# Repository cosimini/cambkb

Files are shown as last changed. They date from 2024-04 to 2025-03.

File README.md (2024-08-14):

# Yet another split keyboard with low profile Gateron switches

**Important note: tested, it works**
Now the hard part, try getting used to it.

**WARNING:** There's a mistake in the RJ-9 connector routing, I didn't consider that RJ9 cables are typically crimped mirrored, so a custom cable has to be made in order to use the design.

Basically a replica of any other split keyboard project you can find on github
* Pro micro controller
* Gateron low profile KS-33 switches with hot-swap sockets
* No OLED screen, LEDs or other shiny stuff

The main difference in the layout is that the positions of the thumb-keys is moved to the center with respect to more famous keyboards like the Lily58, more like the Voyager.
Vertical stagging of about 1/4 of a key size is applied in the vertical direction, between columns.
The distance between switches is 19mm and not 19.05mm like many other, I don't care it's not 3/4 of an inch.

The PCB is designed using KiCad. It is the same for both right and left side, depending on where components are soldered.
There's no 3D printed case or key support mask, but I'd like to implement it.

The reason for the double socket for the controller is that I was usure on which side I'd like to put the controller.

For the time being I'm not planning to implement QMK or similar things, key map is hardcoded in the code.
The code is based on the Arduino library because I'm lazy. For the same reason I'm using PlatformIO.

For the used switches and controller lib/footprint, credit to [foostan/kdb](https://github.com/foostan/kbd/tree/main).

# BOM
* Controllers: Any pro-micro close is fine, I used the cheapest one I found on Amazon. You can buy presoldered ones, the PCB is compatible with any orientation.
* Switches: Gatheron low profile switches, KS-33 footprint, I used [those ones](https://www.gateron.com/products/gateron-ks-33-low-profile-20-banana-switch?VariantsId=10734).
* Sockets for the switches: The ones associated to the KS-33 footprint ([those](https://www.gateron.com/products/gateron-low-profile-switch-hot-swap-pcb-socket?VariantsId=10234)).
* Diodes: BAT85 are the ones I used, but any signal diode with similar specs should be fine.
* Resistors: There's a resistor in series to the voltage sourcing pin. To prevent accidental shorts, a 1k resistor is placed in series. Those can be replaced by a jumper wire. Note I used DIN0204, a kind of small size trough hole package.
* Sockets for the controller: If you don't want to solder the controllers to the PCB, you can use any 2.54mm socket.
* RJ9 socket: It is a standard, any trough hole socket is fine.
* RJ9 Cable: **WARNING** as mentioned above, you need to make your own cable, as the common telephone ones has mirrored connected plugs at each end (i.e. in my design each cable must end on the same size of the plug).

# Pictures of the result





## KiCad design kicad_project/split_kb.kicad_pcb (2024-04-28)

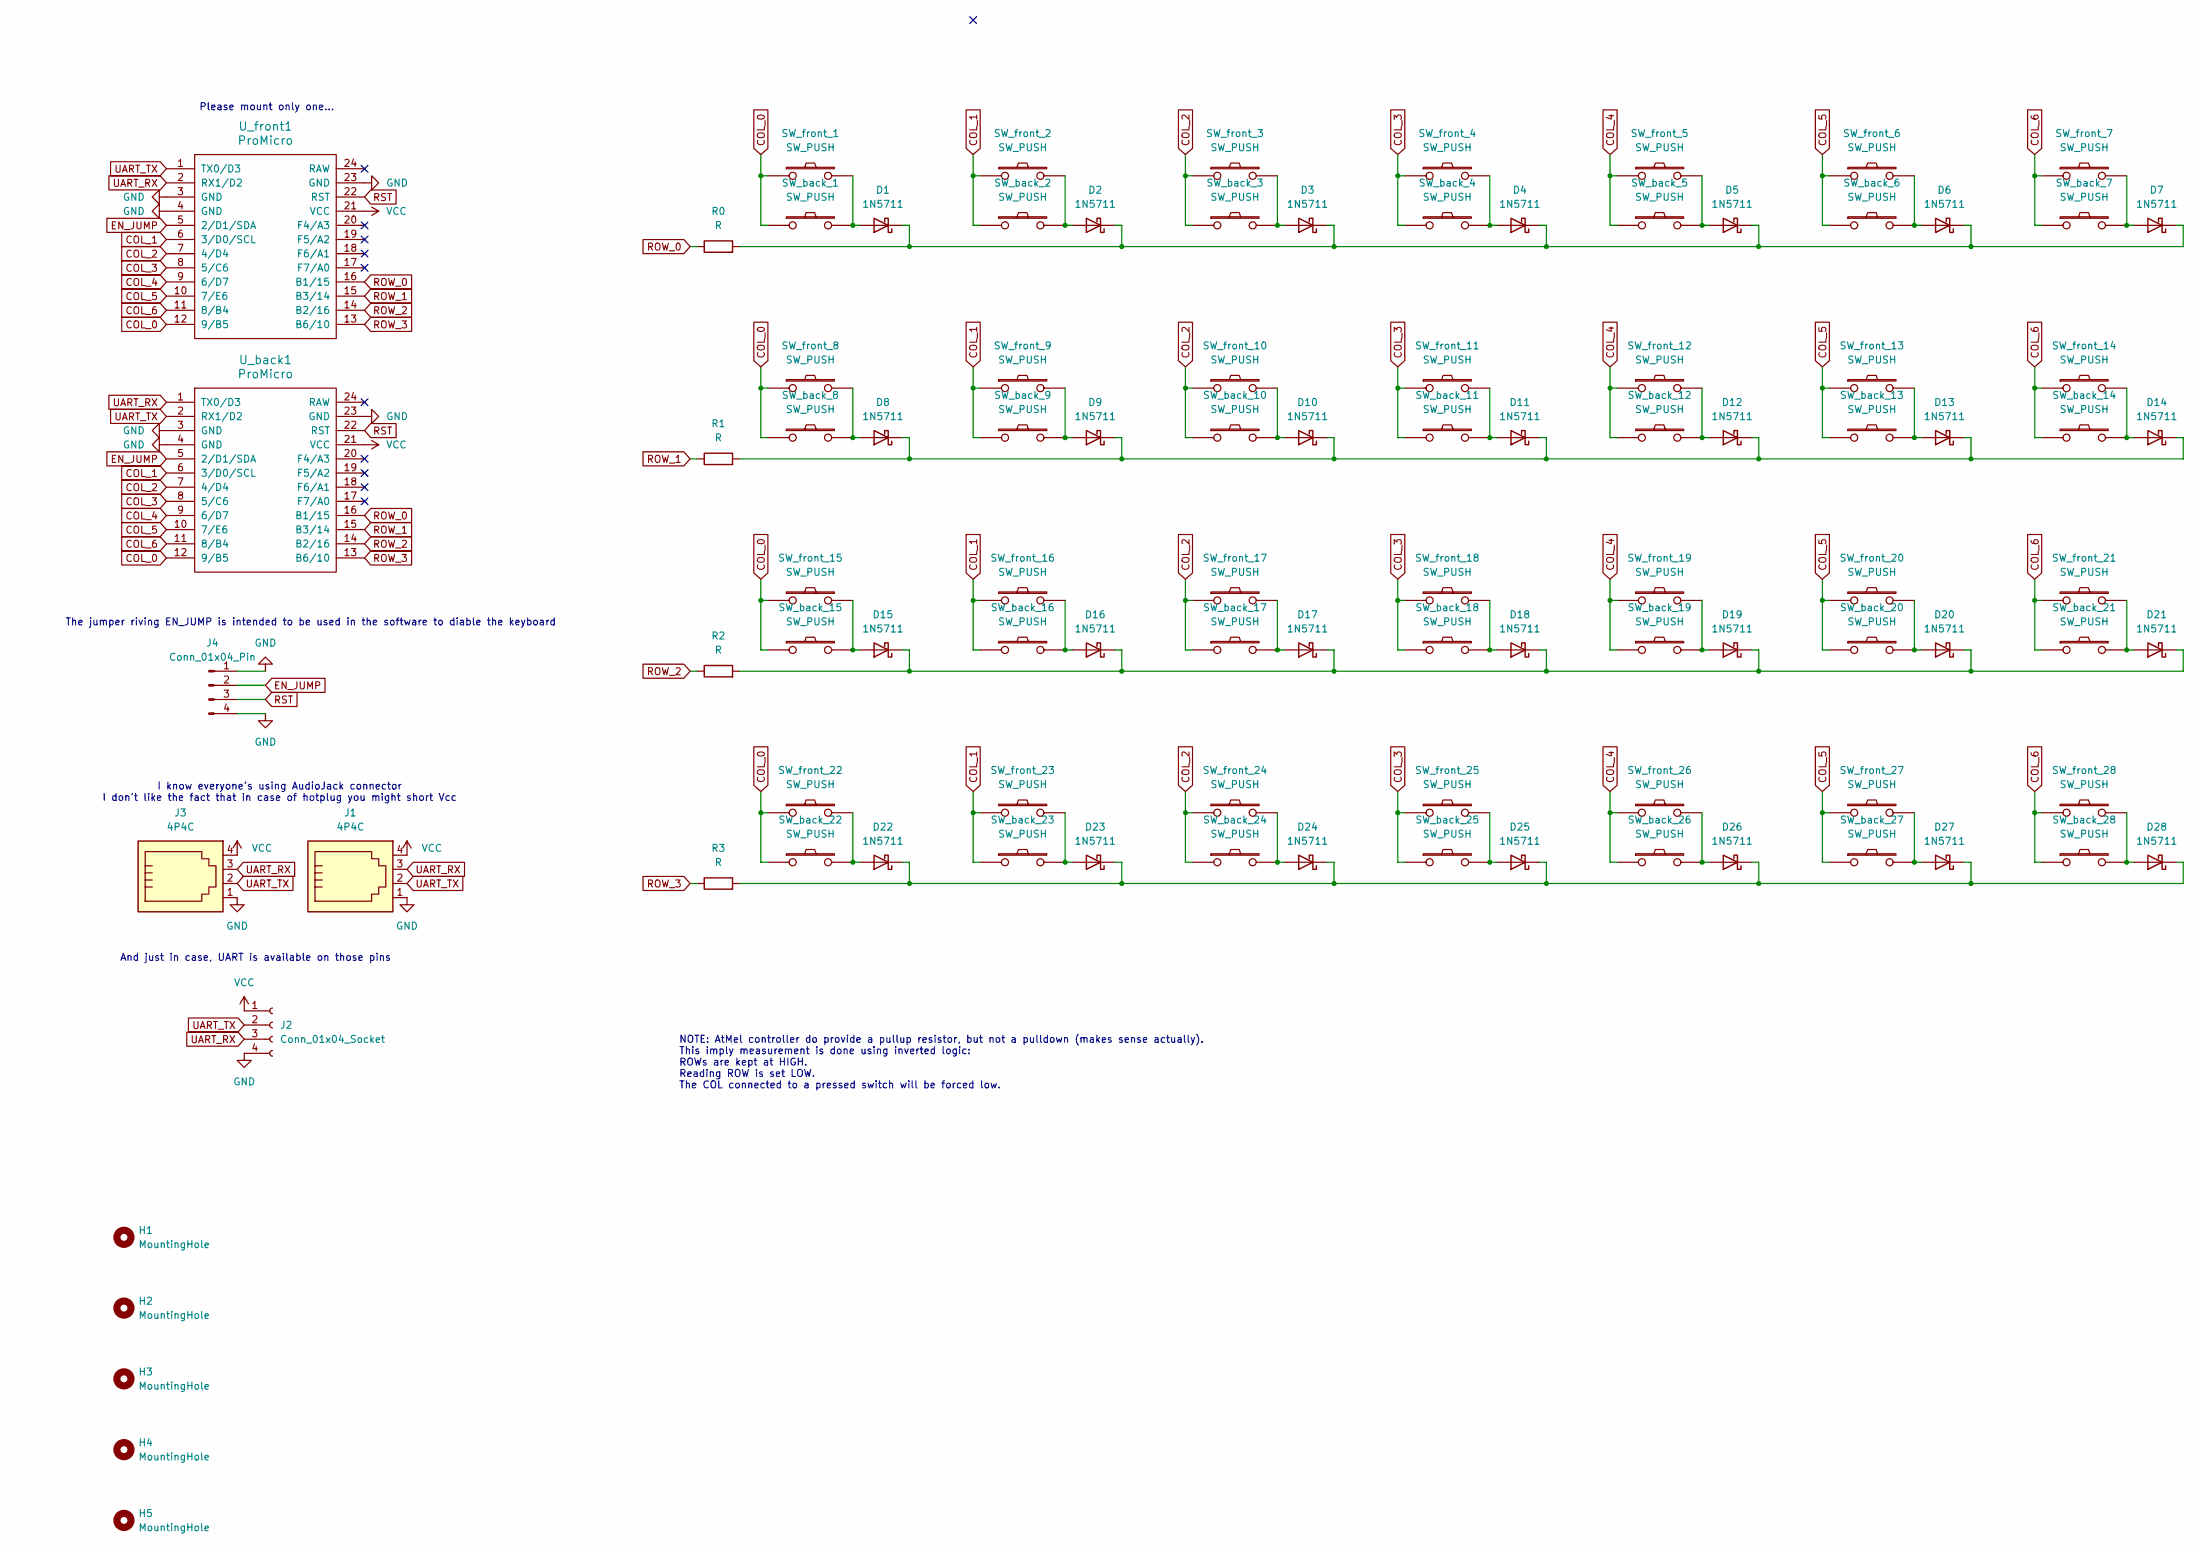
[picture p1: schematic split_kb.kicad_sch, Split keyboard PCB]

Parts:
D1, D2, D3, D4, D5, D6, D7, D8, D9, D10, D11, D12, D13, D14, D15, D16, D17, D18, D19, D20, D21, D22, D23, D24, D25, D26, D27, D28: 1N5711; D_DO-35_SOD27_P7.62mm_Horizontal
H1, H2, H3, H4, H5: MountingHole; MountingHole_3mm_Pad_Via
J1, J3: 4P4C; RJ9_Evercom_5301-440xxx_Horizontal
J2: Conn_01x04_Socket; PinHeader_1x04_P2.54mm_Vertical
J4: Conn_01x04_Pin; PinHeader_1x04_P2.54mm_Vertical
R0, R1, R2, R3: R; R_Axial_DIN0204_L3.6mm_D1.6mm_P5.08mm_Horizontal
SW_back_1, SW_back_2, SW_back_3, SW_back_4, SW_back_5, SW_back_6, SW_back_7, SW_back_8, SW_back_9, SW_back_10, SW_back_11, SW_back_12, SW_back_13, SW_back_14, SW_back_15, SW_back_16, SW_back_17, SW_back_18, SW_back_19, SW_back_20, SW_back_21, SW_back_22, SW_back_23, SW_back_24, SW_back_25, SW_back_26, SW_back_27, SW_back_28: SW_PUSH; keyswitch_gateron_low_profile_hotswap_1u
SW_front_1, SW_front_2, SW_front_3, SW_front_4, SW_front_5, SW_front_6, SW_front_7, SW_front_8, SW_front_9, SW_front_10, SW_front_11, SW_front_12, SW_front_13, SW_front_14, SW_front_15, SW_front_16, SW_front_17, SW_front_18, SW_front_19, SW_front_20, SW_front_21, SW_front_22, SW_front_23, SW_front_24, SW_front_25, SW_front_26, SW_front_27, SW_front_28: SW_PUSH; keyswitch_gateron_low_profile_hotswap_1u
U_back1: ProMicro
U_front1: ProMicro

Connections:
COL_0: SW_back_1.1, SW_back_8.1, SW_back_15.1, SW_back_22.1, SW_front_1.1, SW_front_8.1, SW_front_15.1, SW_front_22.1, U_back1.12 (9/B5), U_front1.12 (9/B5)
COL_1: SW_back_2.1, SW_back_9.1, SW_back_16.1, SW_back_23.1, SW_front_2.1, SW_front_9.1, SW_front_16.1, SW_front_23.1, U_back1.6 (3/D0/SCL), U_front1.6 (3/D0/SCL)
COL_2: SW_back_3.1, SW_back_10.1, SW_back_17.1, SW_back_24.1, SW_front_3.1, SW_front_10.1, SW_front_17.1, SW_front_24.1, U_back1.7 (4/D4), U_front1.7 (4/D4)
COL_3: SW_back_4.1, SW_back_11.1, SW_back_18.1, SW_back_25.1, SW_front_4.1, SW_front_11.1, SW_front_18.1, SW_front_25.1, U_back1.8 (5/C6), U_front1.8 (5/C6)
COL_4: SW_back_5.1, SW_back_12.1, SW_back_19.1, SW_back_26.1, SW_front_5.1, SW_front_12.1, SW_front_19.1, SW_front_26.1, U_back1.9 (6/D7), U_front1.9 (6/D7)
COL_5: SW_back_6.1, SW_back_13.1, SW_back_20.1, SW_back_27.1, SW_front_6.1, SW_front_13.1, SW_front_20.1, SW_front_27.1, U_back1.10 (7/E6), U_front1.10 (7/E6)
COL_6: SW_back_7.1, SW_back_14.1, SW_back_21.1, SW_back_28.1, SW_front_7.1, SW_front_14.1, SW_front_21.1, SW_front_28.1, U_back1.11 (8/B4), U_front1.11 (8/B4)
EN_JUMP: J4.2, U_back1.5 (2/D1/SDA), U_front1.5 (2/D1/SDA)
GND: J1.1, J2.4, J3.1, J4.1, J4.4, U_back1.3 (GND), U_back1.4 (GND), U_back1.23 (GND), U_front1.3 (GND), U_front1.4 (GND), U_front1.23 (GND)
unnamed: D1.2 (A), SW_back_1.2, SW_front_1.2
unnamed: D1.1 (K), D2.1 (K), D3.1 (K), D4.1 (K), D5.1 (K), D6.1 (K), D7.1 (K), R0.2
unnamed: D2.2 (A), SW_back_2.2, SW_front_2.2
unnamed: D3.2 (A), SW_back_3.2, SW_front_3.2
unnamed: D4.2 (A), SW_back_4.2, SW_front_4.2
unnamed: D5.2 (A), SW_back_5.2, SW_front_5.2
unnamed: D6.2 (A), SW_back_6.2, SW_front_6.2
unnamed: D7.2 (A), SW_back_7.2, SW_front_7.2
unnamed: D8.2 (A), SW_back_8.2, SW_front_8.2
unnamed: D9.2 (A), SW_back_9.2, SW_front_9.2
unnamed: D10.2 (A), SW_back_10.2, SW_front_10.2
unnamed: D8.1 (K), D9.1 (K), D10.1 (K), D11.1 (K), D12.1 (K), D13.1 (K), D14.1 (K), R1.2
unnamed: D11.2 (A), SW_back_11.2, SW_front_11.2
unnamed: D12.2 (A), SW_back_12.2, SW_front_12.2
unnamed: D13.2 (A), SW_back_13.2, SW_front_13.2
unnamed: D14.2 (A), SW_back_14.2, SW_front_14.2
unnamed: D15.2 (A), SW_back_15.2, SW_front_15.2
unnamed: D15.1 (K), D16.1 (K), D17.1 (K), D18.1 (K), D19.1 (K), D20.1 (K), D21.1 (K), R2.2
unnamed: D16.2 (A), SW_back_16.2, SW_front_16.2
unnamed: D17.2 (A), SW_back_17.2, SW_front_17.2
unnamed: D18.2 (A), SW_back_18.2, SW_front_18.2
unnamed: D19.2 (A), SW_back_19.2, SW_front_19.2
unnamed: D20.2 (A), SW_back_20.2, SW_front_20.2
unnamed: D21.2 (A), SW_back_21.2, SW_front_21.2
unnamed: D22.2 (A), SW_back_22.2, SW_front_22.2
unnamed: D22.1 (K), D23.1 (K), D24.1 (K), D25.1 (K), D26.1 (K), D27.1 (K), D28.1 (K), R3.2
unnamed: D23.2 (A), SW_back_23.2, SW_front_23.2
unnamed: D24.2 (A), SW_back_24.2, SW_front_24.2
unnamed: D25.2 (A), SW_back_25.2, SW_front_25.2
unnamed: D26.2 (A), SW_back_26.2, SW_front_26.2
unnamed: D27.2 (A), SW_back_27.2, SW_front_27.2
unnamed: D28.2 (A), SW_back_28.2, SW_front_28.2
ROW_0: R0.1, U_back1.16 (B1/15), U_front1.16 (B1/15)
ROW_1: R1.1, U_back1.15 (B3/14), U_front1.15 (B3/14)
ROW_2: R2.1, U_back1.14 (B2/16), U_front1.14 (B2/16)
ROW_3: R3.1, U_back1.13 (B6/10), U_front1.13 (B6/10)
RST: J4.3, U_back1.22 (RST), U_front1.22 (RST)
UART_RX: J1.3, J2.3, J3.3, U_back1.1 (TX0/D3), U_front1.2 (RX1/D2)
UART_TX: J1.2, J2.2, J3.2, U_back1.2 (RX1/D2), U_front1.1 (TX0/D3)
VCC: J1.4, J2.1, J3.4, U_back1.21 (VCC), U_front1.21 (VCC)

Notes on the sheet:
And just in case, UART is available on those pins
Please mount only one...
I know everyone's using AudioJack connector I don't like the fact that in case of hotplug you might short Vcc
NOTE: AtMel controller do provide a pullup resistor, but not a pulldown (makes sense actually). This imply measurement is done using inverted logic: ROWs are kept at HIGH. Reading ROW is set LOW. The COL connected to a pressed switch will be forced low.
The jumper riving EN_JUMP is intended to be used in the software to diable the keyboard

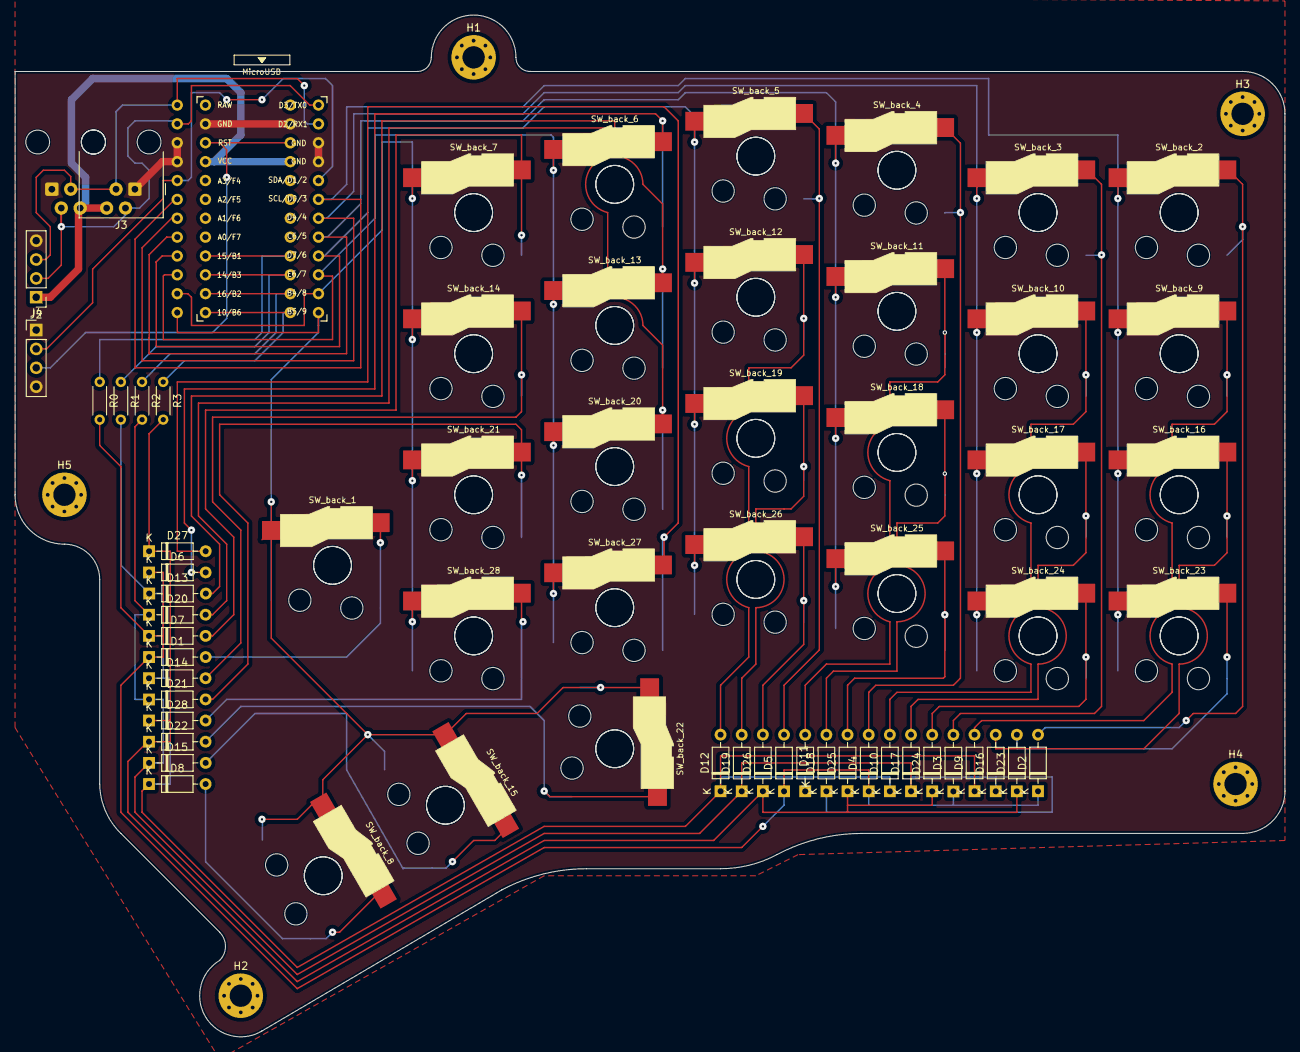
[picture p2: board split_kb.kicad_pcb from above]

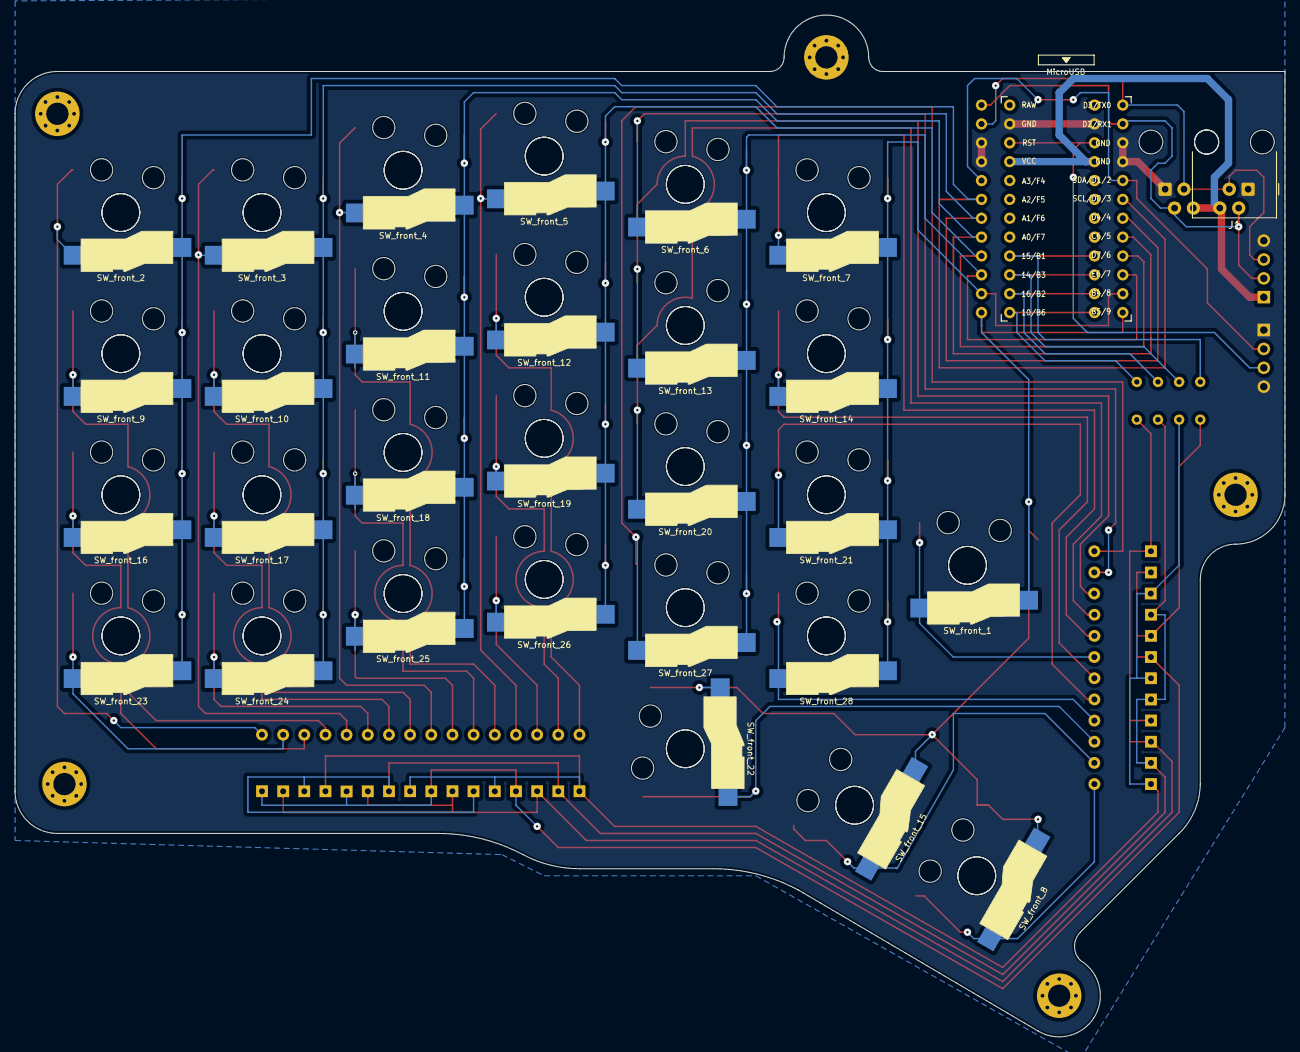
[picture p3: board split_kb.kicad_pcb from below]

Board: 2 copper layers, 171.0 x 137.6 mm, 99 parts (30 on the bottom side), 49 nets.

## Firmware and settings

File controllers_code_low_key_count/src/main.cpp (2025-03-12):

/*
* The code running in the two controllers.
* The two communicate via UART.
* As all the code I write it ended up being a pile of crap.
*/

// TODO: Refactor the mechanism in a more maintenable code
// TODO: Implement the tap-hold logic for modifiers (hold -> modifier, tap (whith no other key) -> char (e.g. space)
// TODO: Implement the tap-hold logic for characters (tap -> a ; hold > threshold -> A)
// TODO: Implement the tap-sequence logic (a,b -> arrow, a,a -> a)

#define SIDE 1        // Select the keymap to save in the device memory
#define MOD_CHAR 'm'  // Char sent by both parties before sending the modifier sum value
#define LOOP_DELAY 5

#include "Arduino.h"
#include "Keyboard.h"
#include "pinout.h"   // Microcontroller pinout
#include "keymaps.h"  // Map between keys and sent codes

int col_pins[N_COLS] = { COL0, COL1, COL2, COL3, COL4, COL5, COL6 };  // Map between columns number and pin
int row_pins[N_ROWS] = { ROW0, ROW1, ROW2, ROW3 };                    // Map between rows number and pin
bool status[2][N_ROWS][N_COLS]; // Status vector. It contains the status of each individial switch.
int statusPointer = 0;          // The value toggle between 0 and 1 to select the status matrix
bool isMaster;                  // Only one side is sending kewystrokes, the selection is done with a jumper

// Scan the switches matrix and update status[]
void matrix_scan() {
  statusPointer = (statusPointer == 1) ? 0 : 1;  // Toggle the status pointer.
  for(int k = 0; k < N_ROWS; k++) digitalWrite(row_pins[k], HIGH); // Set all to HIGH as the electronics works with inverted logic
  for(int k = 0; k < N_ROWS; k++) {
    digitalWrite(row_pins[k], LOW);
    for(int i = 0; i < N_COLS; i++) status[statusPointer][k][i] = !digitalRead(col_pins[i]); // Scan the column
    digitalWrite(row_pins[k], HIGH);
  }
  for(int k = 0; k < N_ROWS; k++) digitalWrite(row_pins[k], LOW); // Disable the outputs.
}

// Arduino setup method
void setup() {
  pinMode(EN_PIN, INPUT_PULLUP);
  for(int k = 0; k < N_ROWS; k++) pinMode(row_pins[k], OUTPUT);
  for(int k = 0; k < N_COLS; k++) pinMode(col_pins[k], INPUT_PULLUP);
  Serial1.begin(115200);
  for(int i = 0; i < 2; i++) {
    for(int j = 0; j < N_ROWS; j++) {
      for(int k = 0; k < N_COLS; k++) {
        status[i][j][k] = false;
      }
    }
  }
  isMaster = digitalRead(EN_PIN); // Master is selected with a jumper
  if(isMaster) Keyboard.begin();
}

// Main loop
void loop() {
  // TODO: The logic needs to be moved entirely in the master side to easily implement the new hold-tap stuff.
}

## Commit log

2024-04-14 Add kicad project.
    [kb_pcb.kicad_pcb, kb_pcb.kicad_sch]
2024-04-19 Done the hard operation of traking between holes
    [kb_pcb.kicad_pcb, kb_pcb.kicad_sch, split_kb.kicad_pcb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]
2024-04-19 Add gitignore (again)
    [split_kb.kicad_pcb]
2024-04-21 Completed first draft of the PCB
    [split_kb.kicad_pcb, split_kb.kicad_sch]
2024-04-22 Fixed edge cut error, changed vertical stagging a bit
    [split_kb.kicad_pcb]
2024-04-22 Moved one of the holes up
    [split_kb.kicad_pcb]
2024-04-22 Grounded EN pin, moved a mounting hole
    [split_kb.kicad_pcb, split_kb.kicad_sch]
2024-04-23 Remove pushbutton library (I removed the reset switch)
2024-04-27 Move trace far from mounting hole, add screenshot
    [split_kb.kicad_pcb]
2024-04-28 Generated production files for JLCPCB
    [split_kb-B_Cu.gbl, split_kb-B_Fab.gbr, split_kb-B_Mask.gbs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]
2024-05-09 PCB arrived! Writing some test code
2024-05-11 FOUND THE BUG: I was configuring the pins up to n_row, not up to n_cols
    [main.cpp]
2024-05-25 Replace variable with define
    [main.cpp]
2024-05-30 Some work on the code (and the cable socket has wrong connections)
    [main.cpp]
2024-06-01 First, failed, tentative of making the code work
    [main.cpp]
2024-06-02 Half of the kb is working, unable to send keystrokes over UART ATM
2024-06-03 Test the UART communication
2024-06-11 Fix slave layers, update keymap
    [main.cpp]
2024-06-16 Add cable error warning
2024-06-16 Replace come const with compiler definitions
    [main.cpp]
2024-08-14 Add BOM description
    Did not include links for stuff that can be found from different distributors
